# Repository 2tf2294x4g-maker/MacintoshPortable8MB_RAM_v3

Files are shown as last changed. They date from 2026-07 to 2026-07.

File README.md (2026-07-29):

# Mac Portable 8MB RAM Card (v3 — All-5V)

Expands a Macintosh Portable to **9 MB total** (1 MB onboard + 8 MB this card) — the maximum the Portable's address space supports.

All-5V design using 1M×8 SRAM chips and an ATF1502ASL CPLD. Works with both the **M5120** (non-backlit) and **M5126** (backlit) Portable via the MODEL jumper. Banks are added sequentially — no jumpers needed as you populate.

> ⚠️ **PRE-PRODUCTION — NOT TESTED**
> This board has been designed and ordered but has not yet been assembled or validated on real hardware. Schematics, firmware, and Gerbers are provided as-is. Do not build for production use until hardware validation is complete.

---

## What's new in v3 vs v2

| | v2 | v3 |
|---|---|---|
| Model compatibility | M5120 only | M5120 + M5126 (MODEL jumper) |
| Bank indicator | none | 4 green latching LEDs (one per bank) |
| Ghost RAM protection | none | 10 KΩ pull-downs on SD0–SD15 |
| Population jumper | SIZE jumper (JP1) | none — sequential by design |
| DTACK output | bodge wire to CPLD pad | J3 header (pin 1 = /DTACK, pin 2 = /EXT_DTACK) |
| SRAM count | 8× AS6C8008 | 8× AS6C8008 (same chips) |

---

## Specs

| | |
|---|---|
| Capacity | 8 MB (8× 1M×8 SRAM) |
| System total | 9 MB M5120 (open) / 7 MB M5126 (closed) |
| Bus width | 16-bit (two 8-bit SRAMs per bank) |
| Banks | 4 × 2 MB, populated sequentially |
| Logic | ATF1502ASL CPLD (5V, TQFP-44) |
| SRAM | 8× AS6C8008-55ZIN (5V, TSOP-II-44) |
| Layers | 4 (F.Cu signal / GND plane / +5V plane / B.Cu signal) |
| Connector | Samtec BCS-125-F-D-HE (50-pin 2×25, horizontal entry) |
| MODEL jumper | JP1: OPEN = M5120 non-backlit (9 MB) / CLOSED = M5126 backlit (7 MB) |

---

## Bill of Materials

| Ref | Qty | Value | Package | Part / Notes |
|-----|----:|---|---|---|
| U1–U8 | 8 | AS6C8008-55ZIN | TSOP-II-44 | Alliance Memory — 1M×8 5V SRAM 55 ns. Order spares. |
| U9 | 1 | ATF1502ASL | TQFP-44 | Microchip ATF1502ASL-**25AU44** — must be **ASL** (5V), not ASV |
| U10, U11 | 2 | 74HC245 | SOIC-20 **wide** | SN74HC245**DW** — verify wide (7.5 mm) body |
| J1 | 1 | RAM connector | Samtec BCS-125-F-D-HE | 50-pin socket, horizontal entry |
| J2 | 1 | JTAG header | 1×6 2.54 mm pin header | GND/VCC/TDO/TDI/TMS/TCK left-to-right |
| J3 | 1 | PDS DTACK header | 1×2 2.54 mm pin header | Pin 1 = /DTACK → PDS B7, Pin 2 = /EXT_DTACK → PDS B30 |
| JP1 | 1 | MODEL jumper | 1×2 2.54 mm pin header + shunt | OPEN = M5120 / CLOSED = M5126 |
| D1–D4 | 4 | Green LED | 0603 | Latch ON at boot when each bank is confirmed by the CPLD |
| R1–R4 | 4 | 330 Ω | 0402 | Series resistors for D1–D4 |
| R5–R20 | 16 | 10 KΩ | 0402 | Pull-downs on SD0–SD15 (SRAM side of 74HC245) — prevent ghost RAM |
| R21–R24 | 4 | 10 KΩ | 0805 | Pull-ups on CPLD unused inputs and MODEL jumper pin |
| C1–C14 | 14 | 100 nF | 0805 | X7R 50V ceramic bypass (one per IC) |
| C15–C19 | 5 | 10 µF | 0805 | X5R 16V ceramic bulk |

Full BOM: [PortableRAM-8MB-v3-BOM.csv](PortableRAM-8MB-v3-BOM.csv)

---

## ⚠️ Important — SRAM Pinout

The AS6C8008 (1M×8) and AS7C4096A (512K×8 used in the 4MB card) are **both TSOP-II-44 but have different pinouts**. Do not mix them between boards.

---

## Population Guide

Banks are populated sequentially — each pair of SRAMs adds 2 MB. No jumpers required.

| Step | Chips | Total RAM |
|---|---|---|
| 1 | U1 + U5 | 2 MB |
| 2 | U2 + U6 | 4 MB |
| 3 | U3 + U7 | 6 MB |
| 4 | U4 + U8 | 8 MB |

The green LED for each bank (D1–D4) latches on at boot when the CPLD confirms that bank is active. A dark LED means the bank is not yet populated.

---

## MODEL Jumper (JP1)

| JP1 | Portable model | System RAM |
|-----|---|---|
| Open (no shunt) | M5120 non-backlit | 9 MB |
| Closed (shunt installed) | M5126 backlit | 7 MB |

The M5126 uses slot CS0 for its backlight controller, which conflicts with the top 2 MB bank. Closing JP1 disables that bank so the two don't fight. Leave open for M5120.

---

## Files

```
PortableRAM-8MB.kicad_pcb     — PCB layout (KiCad 9)
PortableRAM-8MB.kicad_sch     — Schematic
PortableRAM-8MB.kicad_pro     — Project file
PortableRAM.kicad_sym         — Custom symbol library
PortableRAM.pretty/           — Custom footprint library
Library.pretty/               — Additional footprints
Gerbers/                      — Gerber + drill files (ready to order)
PortableRAM-8MB-v3-Gerbers.zip — Same, zipped (upload directly to fab)
firmware/
  PortableRAM8_v3.pld            — CUPL source (ATF1502ASL logic)
  PortableRAM8_v3.jed            — Compiled JEDEC fusemap
  PortableRAM8_v3.svf            — SVF for OpenOCD programming
  PortableRAM8_v3.fit            — WinCUPL fit report
  program.sh                  — One-command programming script (Tigard)
  BUILD.md                    — Firmware build instructions (WinCUPL + Wine)
PortableRAM-8MB-v3-BOM.csv
```

---

## Ordering the PCB

Upload `PortableRAM-8MB-v3-Gerbers.zip` to your preferred fab (JLCPCB, PCBWay, OSHPark, etc.).

**Board settings:**
- Layers: **4**
- Thickness: 1.6 mm
- Surface finish: **ENIG** (recommended — fine-pitch 0.8 mm pads on TSOP-II-44 and TQFP-44)
- All other settings: fab defaults

---

## Assembly Notes

Solder in this order:

1. **U9** (ATF1502ASL CPLD, TQFP-44) — center first, then drag-solder
2. **U1–U8** (SRAM, TSOP-II-44) — fine pitch; flux generously. Populate in bank pairs: U1+U5 → U2+U6 → U3+U7 → U4+U8
3. **U10, U11** (74HC245, SOIC-20 wide)
4. **R5–R20** (10 KΩ 0402 pull-downs)
5. **R1–R4** (330 Ω 0402 LED resistors)
6. **R21–R24** (10 KΩ 0805 pull-ups)
7. **C1–C14** (100 nF 0805 bypass caps)
8. **C15–C19** (10 µF 0805 bulk caps)
9. **D1–D4** (green 0603 LEDs — observe polarity)
10. **JP1** (1×2 header — add shunt for M5126, leave open for M5120)
11. **J2** (1×6 JTAG header)
12. **J3** (1×2 PDS DTACK header — on board edge)
13. **J1** (Samtec connector) — last

---

## Programming the CPLD

The ATF1502ASL must be programmed before the card will work. Use J2 (1×6 header on the board edge).

### J2 pinout (left to right, component side)

| Pin | Signal |
|-----|---|
| 1 | GND |
| 2 | VCC |
| 3 | TDO |
| 4 | TDI |
| 5 | TMS |
| 6 | TCK |

### With a Tigard programmer (FT2232H-based)

Set the Tigard voltage jumper to **5V** before connecting.

```bash
cd firmware
./program.sh PortableRAM8_v3.svf
```

Success output ends with `shutdown command invoked` and no TDO mismatch errors.

See [firmware/BUILD.md](firmware/BUILD.md) for the full build and programming pipeline (WinCUPL + Wine on Linux, prjbureau for SVF generation).

---

## Installation

1. Power off and unplug the Mac Portable.
2. Remove the battery and bottom cover.
3. Set JP1 (MODEL jumper) for your machine — open for M5120, closed for M5126.
4. Seat the card on the RAM expansion header — J1 is a friction-fit horizontal-entry socket.
5. Reassemble and power on.

With a full build (all 8 SRAMs), you should see **9 MB** in About This Macintosh (M5120) or **7 MB** (M5126). All four green LEDs D1–D4 will be lit.

### DTACK Performance Fix — J3 header

The Mac Portable's GLU chip generates /DTACK for the 68000 with region-dependent timing:

| Address range | GLU /DTACK | Condition |
|---|---|---|
| 0x000000–0x4FFFFF | 2 clocks | Always — hardwired fast path |
| 0x500000–0x8FFFFF | 6 clocks | Normal operation (register configured) |
| 0x500000–0x8FFFFF | 18 clocks | After sleep/wake (register reset) |

The 8 MB card spans 0x100000–0x8FFFFF, straddling the split. Banks 0–1 (0x100000–0x4FFFFF) already get the GLU's 2-clock fast path. Banks 2–3 (0x500000–0x8FFFFF) run at 6 clocks and collapse to 18 clocks after sleep/wake when the GLU's DTACK register loses its configuration.

The fix is built into v3: the CPLD asserts /DTACK directly via **J3 pin 1**, bypassing the GLU for all card accesses. Connect a wire from J3 pin 1 to **PDS slot pin B7** (/DTACK) on the Mac Portable motherboard. The CPLD's path is purely combinatorial — faster than even the GLU's 2-clock mode — and immune to sleep/wake state loss.

J3 pin 2 (/EXT_DTACK → PDS B30) is an optional second output for experimentation.

**Validated on v2 hardware (July 2026):**

| Configuration | Speedometer | Snooper | Post-sleep |
|---|---|---|---|
| 1 MB card (baseline) | 1.990 | 87% | 1.985 |
| 8 MB card — no DTACK fix | 1.486 | 51% | 0.974 / 22% |
| **8 MB card + CPLD DTACK** | **2.170** | **102%** | **2.170** |
| **4 MB card + CPLD DTACK** | **2.170** | **102%** | **2.170** |

The CPLD outperforms the GLU's fastest mode (102% vs 87% baseline) because its combinatorial propagation delay is well under one bus clock. Post-sleep collapse is fully eliminated. The 4 MB result confirms the CPLD path is faster than even the GLU's hardwired 2-clock mode — the fix benefits all bank configurations, not just the upper 8 MB range.

The PDS connector is the 96-pin DIN-41612 on the Mac Portable motherboard (3 rows A/B/C, 32 pins each). Pin B7 is in row B, position 7 from the component side.

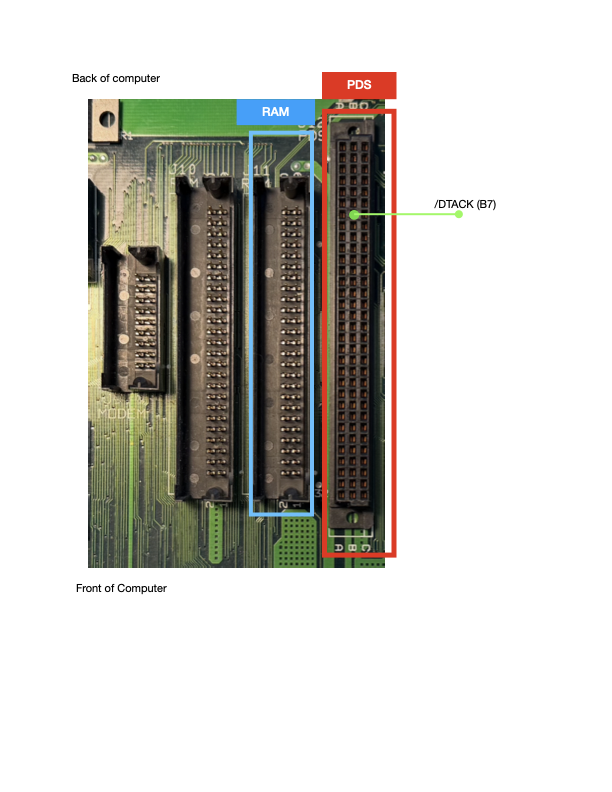
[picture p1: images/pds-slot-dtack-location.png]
PDS slot and RAM connector locations, with /DTACK (B7) marked


---

## References & Acknowledgements

**Dynamic Engineering Mac Portable RAM Card**
The address decode and bus control logic in `PortableRAM8_v3.pld` is derived from GAL22V10 PLD source files originally written for the Dynamic Engineering commercial RAM expansion card. These files define the core signal equations — bank chip-select generation, byte-lane write control via UDS*/LDS*, bus transceiver direction, and output enable timing. The original `.PLD` files were recovered and shared by *techknight* on the TinkerDifferent forum and #skunkworks Discord. Translated here from three GAL22V10 chips to a single ATF1502ASL CPLD, with corrections to the `r_w_u` equation and address decode base, and extended for 8MB capacity and M5126 compatibility.

**miejas — Macintosh Portable 4MB Memory Expansion**
[https://github.com/miejas/Macintosh-Portable-4-MB-Memory-Expansion](https://github.com/miejas/Macintosh-Portable-4-MB-Memory-Expansion)
Open-source 4MB RAM card used as a cross-reference for connector pinout, bus transceiver approach, and firmware structure.

**Reza Fouladian — PortableRAM BGA 8MB**
[https://github.com/rezafouladian/PortableRAM-BGA-8MB](https://github.com/rezafouladian/PortableRAM-BGA-8MB)
BGA-format 8MB card using the ATF1502ASV (3.3V CPLD) and SN74LVC4245A level translators. Reference for the 8MB address decode strategy and CPLD pin planning. Reza also provided direct guidance on driving /DTACK from the CPLD and on the Mac Portable PDS connector pinout — specifically confirming that /DTACK is available on PDS pin B7 and can be driven directly from a CPLD output. This insight is the basis for the J3 DTACK header on v3 and the validated bodge fix on v2.

**Apple Mac Portable Developer Notes & Schematics**
Apple's original hardware documentation for the Mac Portable expansion bus, memory map, and GLU register behaviour (including the $FC0200 DTACK register).

---

## License

Hardware released under [CERN-OHL-S v2](https://ohwr.org/cern_ohl_s_v2.txt). Firmware source (`PortableRAM8_v3.pld`) released under MIT.

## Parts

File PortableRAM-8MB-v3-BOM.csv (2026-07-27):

Designator | Qty | Value | Package | Manufacturer | Mfr Part Number | Notes
U1,U2,U3,U4,U5,U6,U7,U8 | 8 | AS6C8008-55ZIN | TSOP-II-44 (10.16x18.41mm P0.8mm) | Alliance Memory | AS6C8008-55ZIN | 1Mx8 SRAM 5V 55ns (Z=TSOP-II pkg); ~$13-15 each; order 1-2 spares; populate sequentially: U1+U5=2MB U2+U6=4MB U3+U7=6MB U4+U8=8MB
U9 | 1 | ATF1502ASL | TQFP-44 (10x10mm P0.8mm) | Microchip | ATF1502ASL-25AU44 | 5V CPLD (ASL = 5V; do NOT order ASV which is 3.3V); program via J2 JTAG header; order a spare
U10,U11 | 2 | 74HC245 | SOIC-20W (7.5mm wide) | TI/Nexperia | SN74HC245DW | Octal bus transceiver 5V; verify WIDE SOIC-20 body (DW/DWR suffix)
J1 | 1 | RAM Connector | Samtec BCS-125-F-D-HE | Samtec | BCS-125-F-D-HE | 50-pin 2x25 2.54mm socket strip; footprint verified vs drawing
J2 | 1 | JTAG Header 1x06 | PinHeader 2.54mm 1x06 vertical | Generic |  | GND/VCC/TDO/TDI/TMS/TCK left-to-right; labeled on silkscreen; for Tigard programmer
J3 | 1 | PDS DTACK header 1x02 | PinHeader 2.54mm 1x02 vertical | Generic |  | Pin 1 = /DTACK -> PDS B7; Pin 2 = /EXT_DTACK -> PDS B30 (optional)
JP1 | 1 | MODEL jumper 1x02 | PinHeader 2.54mm 1x02 vertical | Generic |  | OPEN=M5120 non-backlit (9MB total) / CLOSED=M5126 backlit (7MB total). Add one 2.54mm shunt.
D1,D2,D3,D4 | 4 | GREEN LED | LED_0603 (1608 metric) | Generic |  | Green indicator LEDs; latch ON when Mac boot probe confirms each bank; board top edge
R1,R2,R3,R4 | 4 | 330 | R_0402 (1005 metric) | Generic |  | Series resistors for D1-D4 LEDs; 330 ohm 1% 1/16W
R5,R6,R7,R8,R9,R10,R11,R12,R13,R14,R15,R16,R17,R18,R19,R20 | 16 | 10K | R_0402 (1005 metric) | Generic |  | Pull-down resistors on SD0-SD15 data bus (SRAM side of 74HC245); prevent ghost RAM on unpopulated banks
R21,R22,R23,R24 | 4 | 10K | R_0805 (2012 metric) | Generic |  | Pull-up resistors on CPLD unused inputs (/AS /DELAY_CS /SLEEP) and MODEL jumper JP1 pin; 5% thick film
C1,C2,C3,C4,C5,C6,C7,C8,C9,C10,C11,C12,C13,C14 | 14 | 100nF | C_0805 (2012 metric) | Generic |  | X7R 50V ceramic decoupling; one per SRAM + U9 + U10 + U11; buy strip of 50+
C15,C16,C17,C18,C19 | 5 | 10uF | C_0805 (2012 metric) | Generic |  | X5R 16V ceramic bulk decoupling; buy 10+

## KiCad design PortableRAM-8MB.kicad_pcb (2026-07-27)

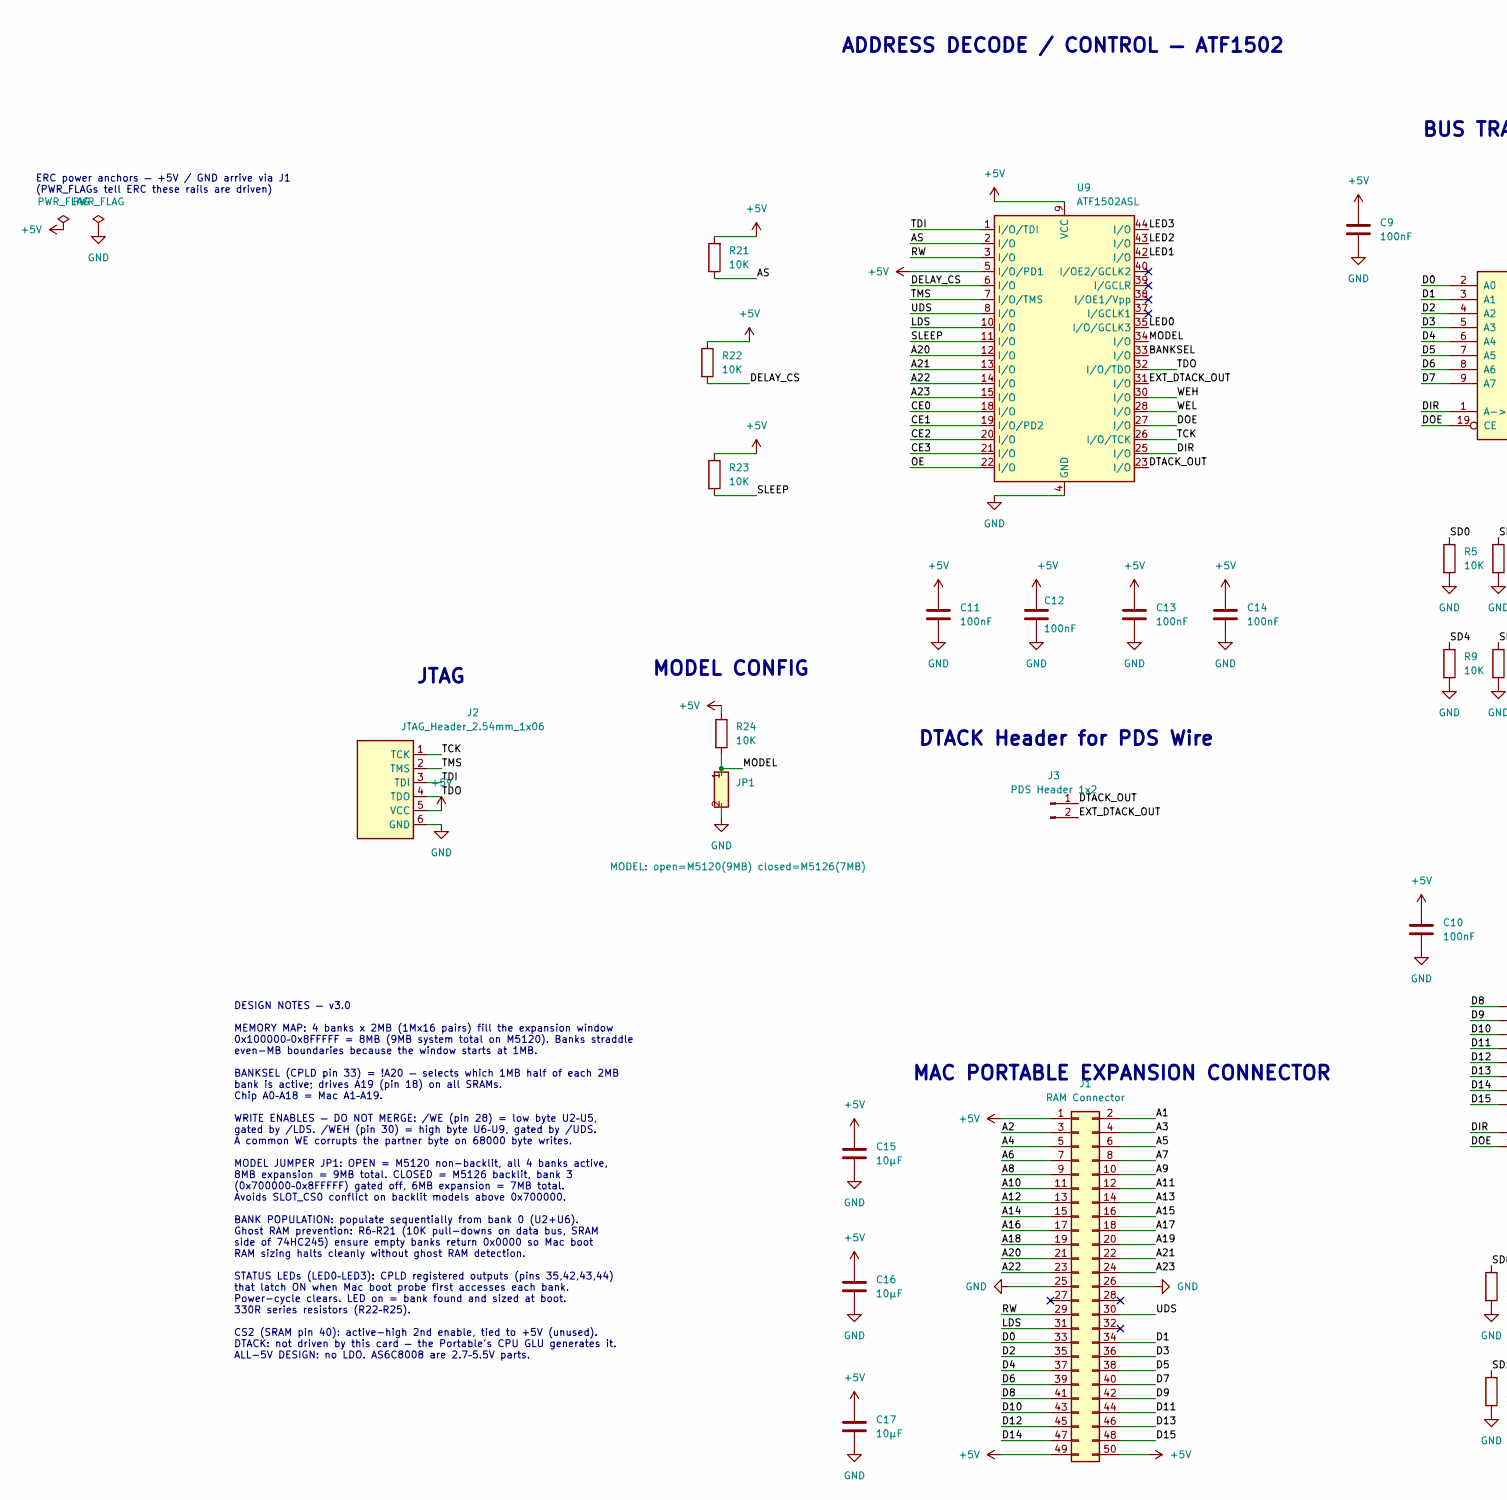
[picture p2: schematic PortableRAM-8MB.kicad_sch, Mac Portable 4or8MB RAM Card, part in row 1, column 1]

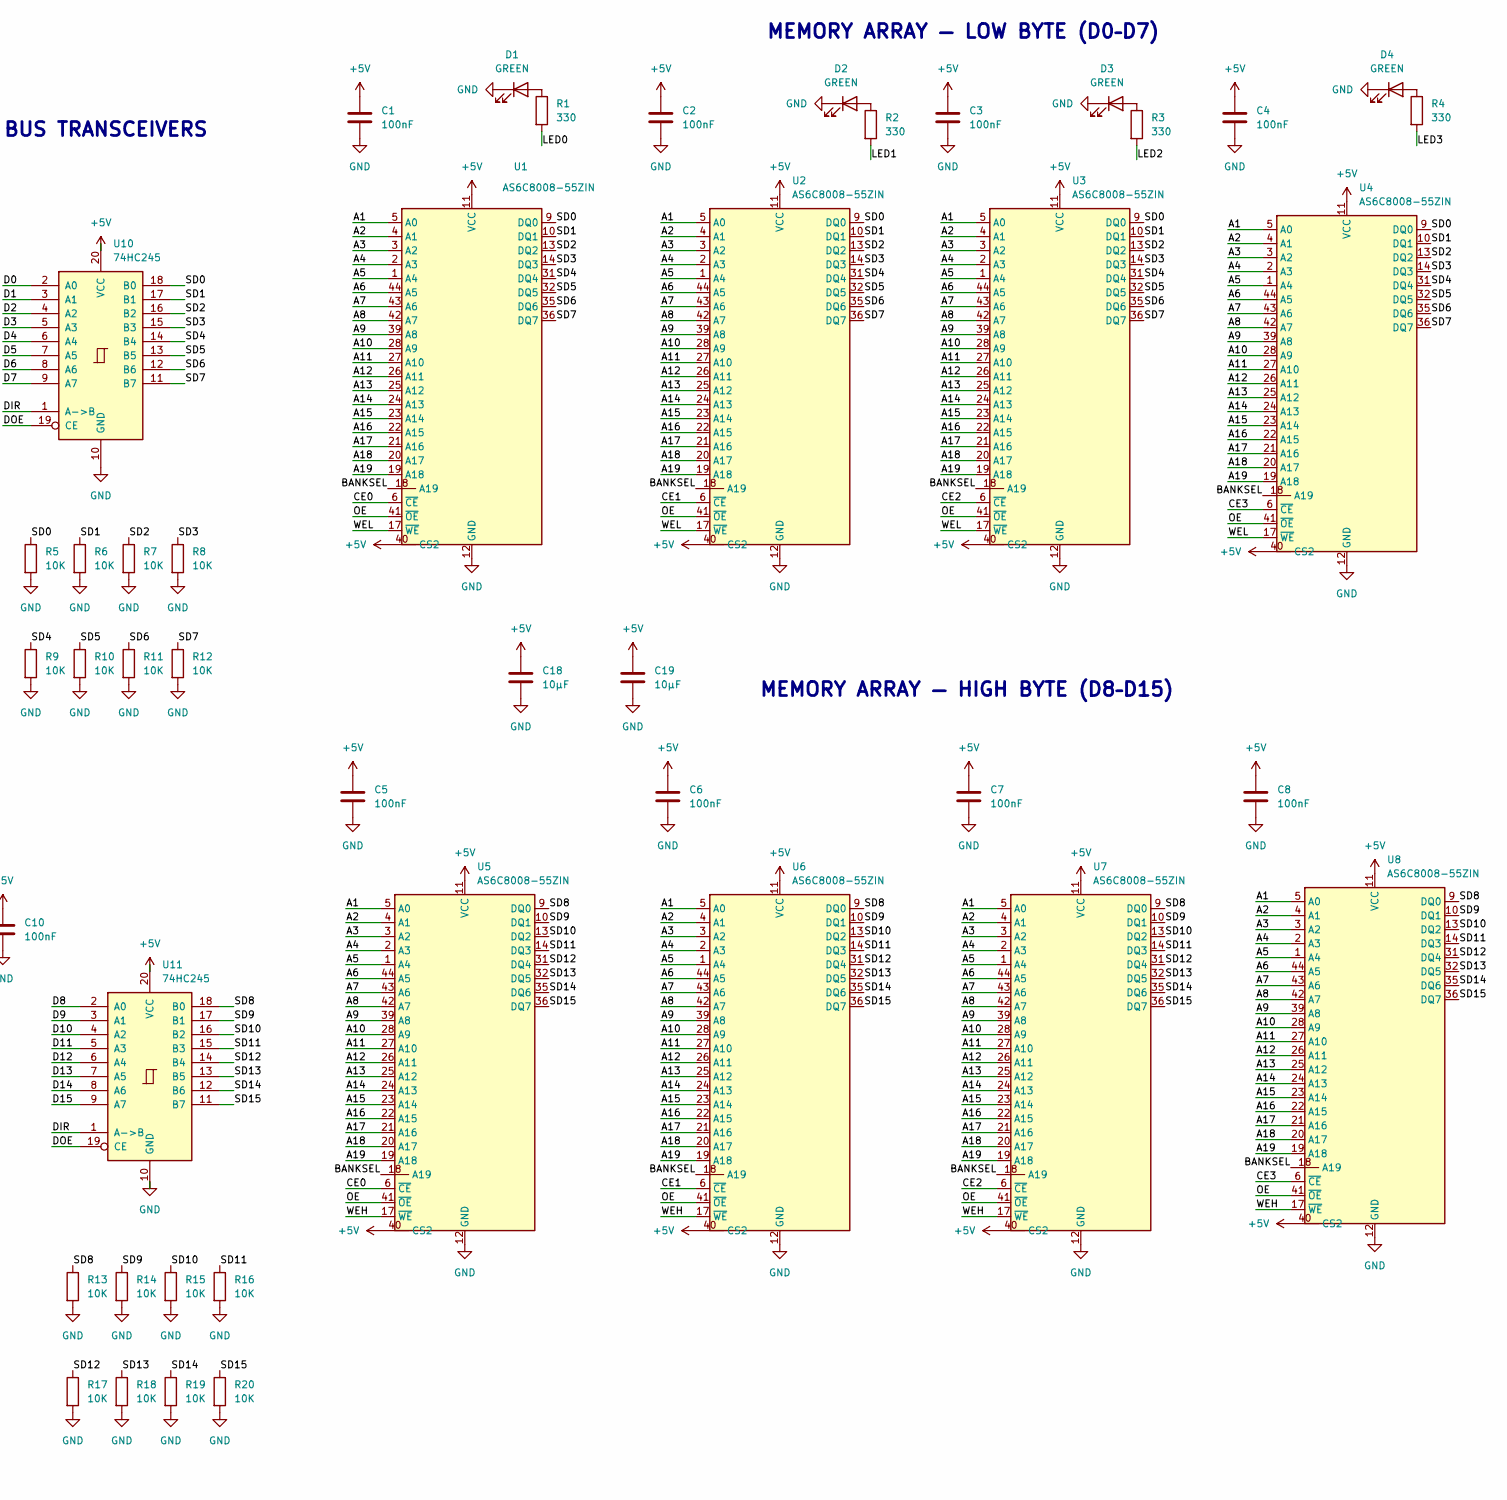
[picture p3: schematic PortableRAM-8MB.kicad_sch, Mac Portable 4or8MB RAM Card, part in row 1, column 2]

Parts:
C1, C2, C3, C4, C5, C6, C7, C8, C9, C10, C11, C12, C13, C14: 100nF; C_0805_2012Metric
C15, C16, C17, C18, C19: 10µF; C_0805_2012Metric
D1, D2, D3, D4: GREEN; LED_0603_1608Metric
J1: RAM Connector; Samtec_BCS-125-F-D-HE
J2: JTAG_Header_2.54mm_1x06; PinHeader_1x06_P2.54mm_Vertical
J3: PDS Header 1x2; PinHeader_1x02_P2.54mm_Vertical
JP1: MODEL: open=M5120(9MB) closed=M5126(7MB); PinHeader_1x02_P2.54mm_Vertical
R1, R2, R3, R4: 330; R_0402_1005Metric
R5, R6, R7, R8, R9, R10, R11, R12, R13, R14, R15, R16, R17, R18, R19, R20: 10K; R_0402_1005Metric
R21, R22, R23, R24: 10K; R_0805_2012Metric
U1, U2, U3, U4, U5, U6, U7, U8: AS6C8008-55ZIN; TSOP-II-44_10.16x18.41mm_P0.8mm
U9: ATF1502ASL; TQFP-44_10x10mm_P0.8mm
U10, U11: 74HC245; SOIC-20W_7.5x12.8mm_P1.27mm

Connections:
+5V: C1.1, C2.1, C3.1, C4.1, C5.1, C6.1, C7.1, C8.1, C9.1, C10.1, C11.1, C12.1, C13.1, C14.1, C15.1, C16.1, C17.1, C18.1, C19.1, J1.1, J1.49, J1.50, J2.5 (VCC), R21.2, R22.1, R23.1, R24.1, U1.11 (VCC), U1.33 (VCC), U1.40 (CS2), U2.11 (VCC), U2.33 (VCC), U2.40 (CS2), U3.11 (VCC), U3.33 (VCC), U3.40 (CS2), U4.11 (VCC), U4.33 (VCC), U4.40 (CS2), U5.11 (VCC), U5.33 (VCC), U5.40 (CS2), U6.11 (VCC), U6.33 (VCC), U6.40 (CS2), U7.11 (VCC), U7.33 (VCC), U7.40 (CS2), U8.11 (VCC), U8.33 (VCC), U8.40 (CS2), U9.5 (I/O/PD1), U9.9 (VCC), U9.17 (VCC), U9.29 (VCC), U9.41 (VCC), U10.20 (VCC), U11.20 (VCC)
/A1: J1.2, U1.5 (A0), U2.5 (A0), U3.5 (A0), U4.5 (A0), U5.5 (A0), U6.5 (A0), U7.5 (A0), U8.5 (A0)
/A2: J1.3, U1.4 (A1), U2.4 (A1), U3.4 (A1), U4.4 (A1), U5.4 (A1), U6.4 (A1), U7.4 (A1), U8.4 (A1)
/A3: J1.4, U1.3 (A2), U2.3 (A2), U3.3 (A2), U4.3 (A2), U5.3 (A2), U6.3 (A2), U7.3 (A2), U8.3 (A2)
/A4: J1.5, U1.2 (A3), U2.2 (A3), U3.2 (A3), U4.2 (A3), U5.2 (A3), U6.2 (A3), U7.2 (A3), U8.2 (A3)
/A5: J1.6, U1.1 (A4), U2.1 (A4), U3.1 (A4), U4.1 (A4), U5.1 (A4), U6.1 (A4), U7.1 (A4), U8.1 (A4)
/A6: J1.7, U1.44 (A5), U2.44 (A5), U3.44 (A5), U4.44 (A5), U5.44 (A5), U6.44 (A5), U7.44 (A5), U8.44 (A5)
/A7: J1.8, U1.43 (A6), U2.43 (A6), U3.43 (A6), U4.43 (A6), U5.43 (A6), U6.43 (A6), U7.43 (A6), U8.43 (A6)
/A8: J1.9, U1.42 (A7), U2.42 (A7), U3.42 (A7), U4.42 (A7), U5.42 (A7), U6.42 (A7), U7.42 (A7), U8.42 (A7)
/A9: J1.10, U1.39 (A8), U2.39 (A8), U3.39 (A8), U4.39 (A8), U5.39 (A8), U6.39 (A8), U7.39 (A8), U8.39 (A8)
/A10: J1.11, U1.28 (A9), U2.28 (A9), U3.28 (A9), U4.28 (A9), U5.28 (A9), U6.28 (A9), U7.28 (A9), U8.28 (A9)
/A11: J1.12, U1.27 (A10), U2.27 (A10), U3.27 (A10), U4.27 (A10), U5.27 (A10), U6.27 (A10), U7.27 (A10), U8.27 (A10)
/A12: J1.13, U1.26 (A11), U2.26 (A11), U3.26 (A11), U4.26 (A11), U5.26 (A11), U6.26 (A11), U7.26 (A11), U8.26 (A11)
/A13: J1.14, U1.25 (A12), U2.25 (A12), U3.25 (A12), U4.25 (A12), U5.25 (A12), U6.25 (A12), U7.25 (A12), U8.25 (A12)
/A14: J1.15, U1.24 (A13), U2.24 (A13), U3.24 (A13), U4.24 (A13), U5.24 (A13), U6.24 (A13), U7.24 (A13), U8.24 (A13)
/A15: J1.16, U1.23 (A14), U2.23 (A14), U3.23 (A14), U4.23 (A14), U5.23 (A14), U6.23 (A14), U7.23 (A14), U8.23 (A14)
/A16: J1.17, U1.22 (A15), U2.22 (A15), U3.22 (A15), U4.22 (A15), U5.22 (A15), U6.22 (A15), U7.22 (A15), U8.22 (A15)
/A17: J1.18, U1.21 (A16), U2.21 (A16), U3.21 (A16), U4.21 (A16), U5.21 (A16), U6.21 (A16), U7.21 (A16), U8.21 (A16)
/A18: J1.19, U1.20 (A17), U2.20 (A17), U3.20 (A17), U4.20 (A17), U5.20 (A17), U6.20 (A17), U7.20 (A17), U8.20 (A17)
/A19: J1.20, U1.19 (A18), U2.19 (A18), U3.19 (A18), U4.19 (A18), U5.19 (A18), U6.19 (A18), U7.19 (A18), U8.19 (A18)
/A20: J1.21, U9.12 (I/O)
/A21: J1.22, U9.13 (I/O)
/A22: J1.23, U9.14 (I/O)
/A23: J1.24, U9.15 (I/O)
/AS: R21.1, U9.2 (I/O)
/BANKSEL: U1.18 (A19), U2.18 (A19), U3.18 (A19), U4.18 (A19), U5.18 (A19), U6.18 (A19), U7.18 (A19), U8.18 (A19), U9.33 (I/O)
/CE0: U1.6 (~CE), U5.6 (~CE), U9.18 (I/O)
/CE1: U2.6 (~CE), U6.6 (~CE), U9.19 (I/O/PD2)
/CE2: U3.6 (~CE), U7.6 (~CE), U9.20 (I/O)
/CE3: U4.6 (~CE), U8.6 (~CE), U9.21 (I/O)
/D0: J1.33, U10.2 (A0)
/D1: J1.34, U10.3 (A1)
/D2: J1.35, U10.4 (A2)
/D3: J1.36, U10.5 (A3)
/D4: J1.37, U10.6 (A4)
/D5: J1.38, U10.7 (A5)
/D6: J1.39, U10.8 (A6)
/D7: J1.40, U10.9 (A7)
/D8: J1.41, U11.2 (A0)
/D9: J1.42, U11.3 (A1)
/D10: J1.43, U11.4 (A2)
/D11: J1.44, U11.5 (A3)
/D12: J1.45, U11.6 (A4)
/D13: J1.46, U11.7 (A5)
/D14: J1.47, U11.8 (A6)
/D15: J1.48, U11.9 (A7)
/DELAY_CS: R22.2, U9.6 (I/O)
/DIR: U9.25 (I/O), U10.1 (A->B), U11.1 (A->B)
/DOE: U9.27 (I/O), U10.19 (CE), U11.19 (CE)
/DTACK_OUT: J3.1, U9.23 (I/O)
/EXT_DTACK_OUT: J3.2, U9.31 (I/O)
/LDS: J1.31, U9.10 (I/O)
/LED0: R1.2, U9.35 (I/O/GCLK3)
/LED1: R2.2, U9.42 (I/O)
/LED2: R3.2, U9.43 (I/O)
/LED3: R4.2, U9.44 (I/O)
/MODEL: JP1.1, R24.2, U9.34 (I/O)
/OE: U1.41 (~OE), U2.41 (~OE), U3.41 (~OE), U4.41 (~OE), U5.41 (~OE), U6.41 (~OE), U7.41 (~OE), U8.41 (~OE), U9.22 (I/O)
/RW: J1.29, U9.3 (I/O)
/SD0: R5.1, U1.9 (DQ0), U2.9 (DQ0), U3.9 (DQ0), U4.9 (DQ0), U10.18 (B0)
/SD1: R6.1, U1.10 (DQ1), U2.10 (DQ1), U3.10 (DQ1), U4.10 (DQ1), U10.17 (B1)
/SD2: R7.1, U1.13 (DQ2), U2.13 (DQ2), U3.13 (DQ2), U4.13 (DQ2), U10.16 (B2)
/SD3: R8.1, U1.14 (DQ3), U2.14 (DQ3), U3.14 (DQ3), U4.14 (DQ3), U10.15 (B3)
/SD4: R9.1, U1.31 (DQ4), U2.31 (DQ4), U3.31 (DQ4), U4.31 (DQ4), U10.14 (B4)
/SD5: R10.1, U1.32 (DQ5), U2.32 (DQ5), U3.32 (DQ5), U4.32 (DQ5), U10.13 (B5)
/SD6: R11.1, U1.35 (DQ6), U2.35 (DQ6), U3.35 (DQ6), U4.35 (DQ6), U10.12 (B6)
/SD7: R12.1, U1.36 (DQ7), U2.36 (DQ7), U3.36 (DQ7), U4.36 (DQ7), U10.11 (B7)
/SD8: R13.1, U5.9 (DQ0), U6.9 (DQ0), U7.9 (DQ0), U8.9 (DQ0), U11.18 (B0)
/SD9: R14.1, U5.10 (DQ1), U6.10 (DQ1), U7.10 (DQ1), U8.10 (DQ1), U11.17 (B1)
/SD10: R15.1, U5.13 (DQ2), U6.13 (DQ2), U7.13 (DQ2), U8.13 (DQ2), U11.16 (B2)
/SD11: R16.1, U5.14 (DQ3), U6.14 (DQ3), U7.14 (DQ3), U8.14 (DQ3), U11.15 (B3)
/SD12: R17.1, U5.31 (DQ4), U6.31 (DQ4), U7.31 (DQ4), U8.31 (DQ4), U11.14 (B4)
/SD13: R18.1, U5.32 (DQ5), U6.32 (DQ5), U7.32 (DQ5), U8.32 (DQ5), U11.13 (B5)
/SD14: R19.1, U5.35 (DQ6), U6.35 (DQ6), U7.35 (DQ6), U8.35 (DQ6), U11.12 (B6)
/SD15: R20.1, U5.36 (DQ7), U6.36 (DQ7), U7.36 (DQ7), U8.36 (DQ7), U11.11 (B7)
/SLEEP: R23.2, U9.11 (I/O)
/TCK: J2.1 (TCK), U9.26 (I/O/TCK)
/TDI: J2.3 (TDI), U9.1 (I/O/TDI)
/TDO: J2.4 (TDO), U9.32 (I/O/TDO)
/TMS: J2.2 (TMS), U9.7 (I/O/TMS)
/UDS: J1.30, U9.8 (I/O)
/WEH: U5.17 (~WE), U6.17 (~WE), U7.17 (~WE), U8.17 (~WE), U9.30 (I/O)
/WEL: U1.17 (~WE), U2.17 (~WE), U3.17 (~WE), U4.17 (~WE), U9.28 (I/O)
GND: C1.2, C2.2, C3.2, C4.2, C5.2, C6.2, C7.2, C8.2, C9.2, C10.2, C11.2, C12.2, C13.2, C14.2, C15.2, C16.2, C17.2, C18.2, C19.2, D1.1 (K), D2.1 (K), D3.1 (K), D4.1 (K), J1.25, J1.26, J2.6 (GND), JP1.2, R5.2, R6.2, R7.2, R8.2, R9.2, R10.2, R11.2, R12.2, R13.2, R14.2, R15.2, R16.2, R17.2, R18.2, R19.2, R20.2, U1.12 (GND), U1.34 (GND), U2.12 (GND), U2.34 (GND), U3.12 (GND), U3.34 (GND), U4.12 (GND), U4.34 (GND), U5.12 (GND), U5.34 (GND), U6.12 (GND), U6.34 (GND), U7.12 (GND), U7.34 (GND), U8.12 (GND), U8.34 (GND), U9.4 (GND), U9.16 (GND), U9.24 (GND), U9.36 (GND), U10.10 (GND), U11.10 (GND); also elsewhere on the board
unnamed: D1.2 (A), R1.1
unnamed: D2.2 (A), R2.1
unnamed: D3.2 (A), R3.1
unnamed: D4.2 (A), R4.1

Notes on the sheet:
JTAG
MAC PORTABLE EXPANSION CONNECTOR
ADDRESS DECODE / CONTROL — ATF1502
BUS TRANSCEIVERS
MEMORY ARRAY — LOW BYTE (D0–D7)
DESIGN NOTES — v3.0 MEMORY MAP: 4 banks x 2MB (1Mx16 pairs) fill the expansion window 0x100000–0x8FFFFF = 8MB (9MB system total on M5120). Banks straddle even-MB boundaries because the window starts at 1MB. BANKSEL (CPLD pin 33) = !A20 — selects which 1MB half of each 2MB bank is active; drives A19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
MEMORY ARRAY — HIGH BYTE (D8–D15)
MODEL CONFIG
DTACK Header for PDS Wire
ERC power anchors — +5V / GND arrive via J1 (PWR_FLAGs tell ERC these rails are driven)

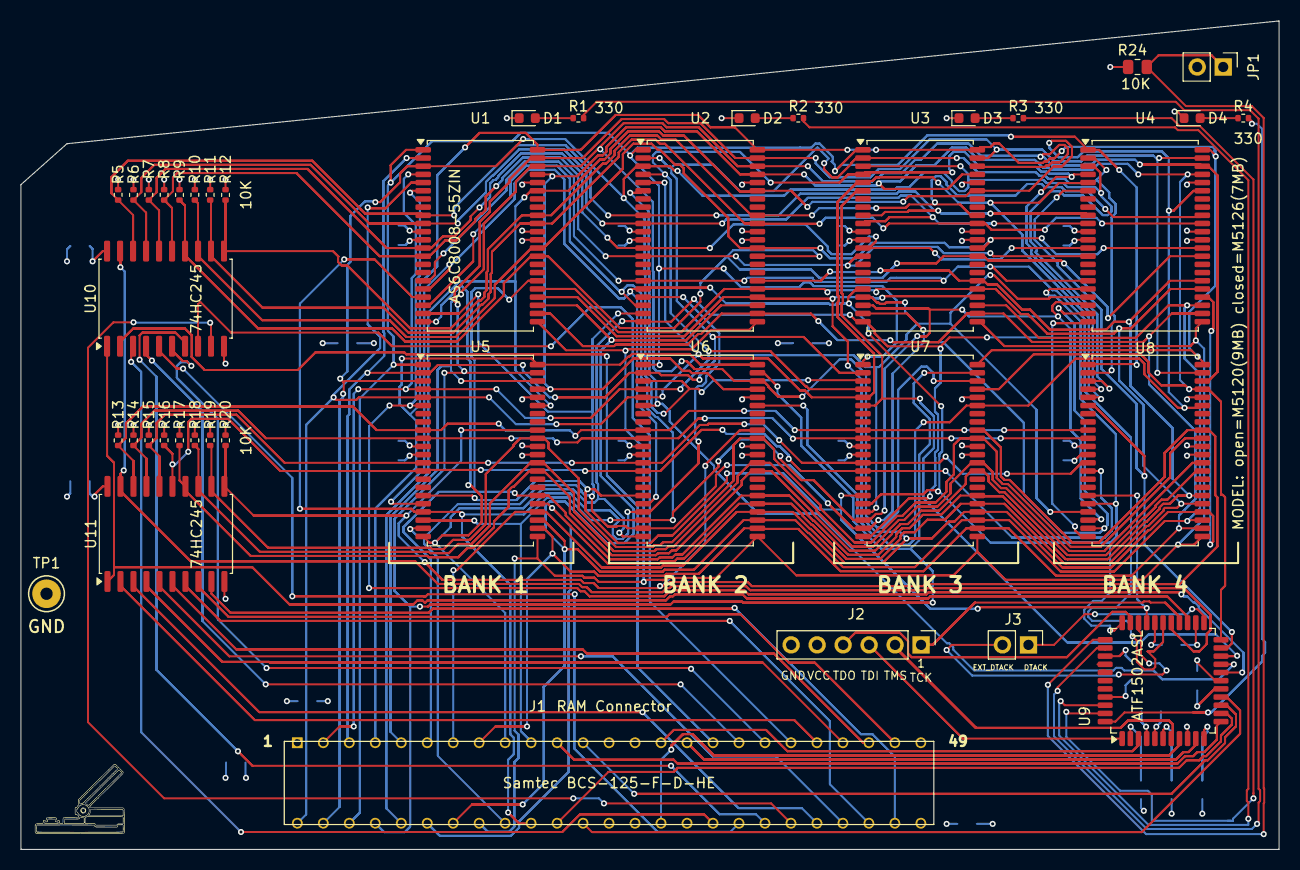
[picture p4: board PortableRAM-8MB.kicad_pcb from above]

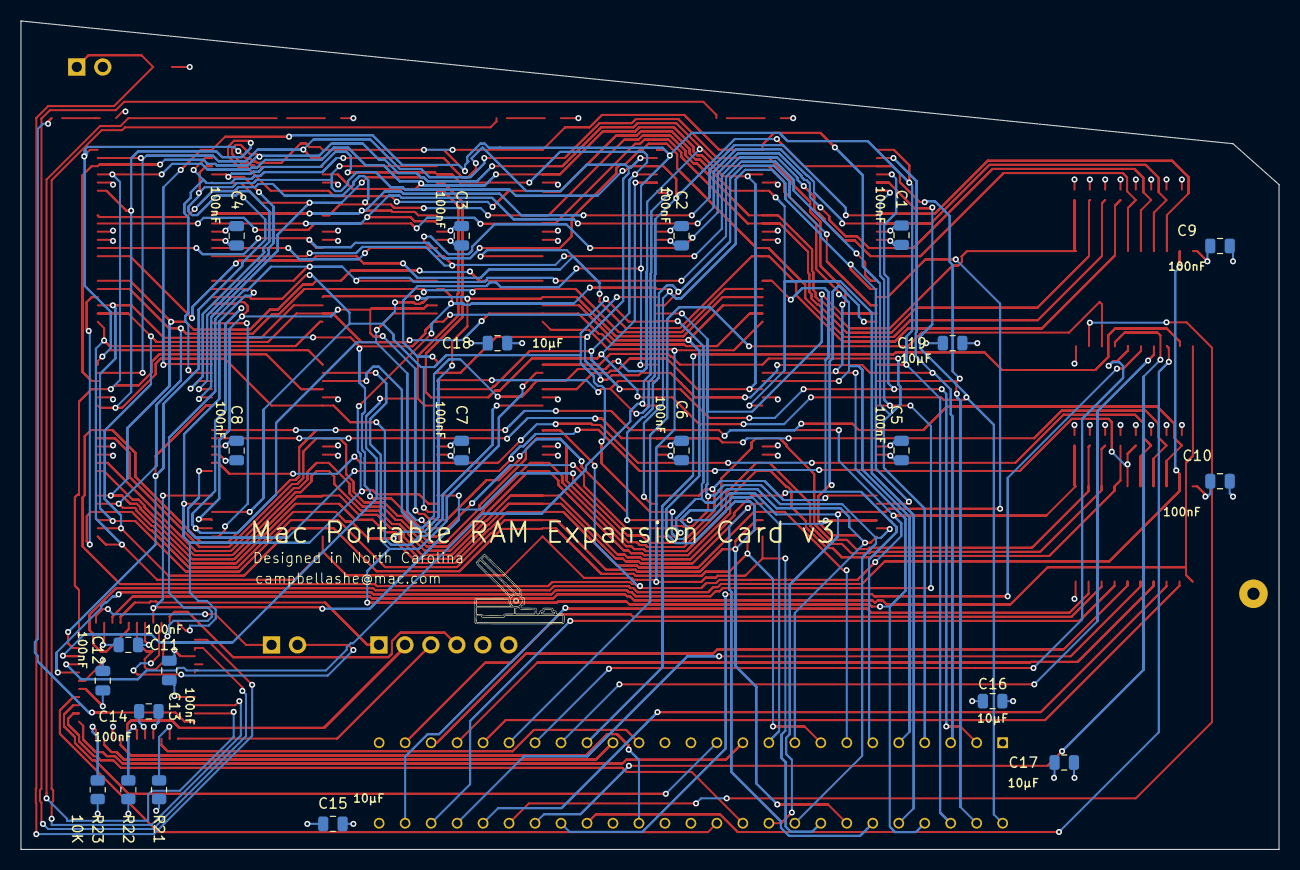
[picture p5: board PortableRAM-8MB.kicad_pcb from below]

Board: 4 copper layers, 123.0 x 81.0 mm, 63 parts (22 on the bottom side), 88 nets.

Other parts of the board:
TP1: GND; TestPoint_GND

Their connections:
GND: TP1.1; also elsewhere on the board

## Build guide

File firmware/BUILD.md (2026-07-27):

# CPLD Firmware Build — CUPL toolchain (Mac + Linux server)

WinCUPL is Windows-only, so we compile on the Ubuntu server under Wine.
Applies to `PortableRAM8.pld` — **v3 8MB board, revision 02**. Do not use with v2 source files.

## Where it's set up (server 192.168.0.52)
- SSH user: `matthew`
- Wine prefix: `~/.wine-cupl` (WINEARCH=win32) with WinCUPL installed at `C:\Wincupl`
- Fitters upgraded to **v1918** (from Atmel ProChip 5.0.1) in `C:\Wincupl\WinCupl\Fitters`
- `5vcomp` wrapper (from github peterzieba/5Vpld) at `/usr/local/bin/5vcomp`

## To compile
```
scp firmware/PortableRAM8.pld matthew@192.168.0.52:~/PortableRAM8_v3.pld
ssh matthew@192.168.0.52 'WINEPREFIX=$HOME/.wine-cupl xvfb-run -a 5vcomp PortableRAM8_v3.pld'
scp matthew@192.168.0.52:~/PortableRAM8_v3.jed firmware/PortableRAM8.jed
scp matthew@192.168.0.52:~/PortableRAM8_v3.fit firmware/PortableRAM8.fit
scp matthew@192.168.0.52:~/PortableRAM8_v3.pin firmware/PortableRAM8.pin
```
Outputs: `.jed` (program this), `.fit` (CHECK pin assignments + "JTAG = ON"), `.pin`.

## .PLD source rules (CUPL is picky — these caused real failures)
1. **Pure ASCII only** — no em-dashes (—), smart quotes, etc. CUPL chokes on UTF-8.
2. **CRLF line endings** — LF-only makes the cuplx preprocessor abort.
3. **No `*/` inside comments** — e.g. write `UDS*, LDS*` NOT `UDS*/LDS*`; the `*/`
   closes the C-style comment early and the rest parses as code.
4. **`PROPERTY ATMEL { jtag = on };`** — keeps JTAG pins live so the Tigard can
   re-program. (Default is ON for the ispTQFP44 device, but be explicit.)

## JED -> SVF (DONE — cross-platform, on the Mac, no Wine)
Uses fuseconv from whitequark/prjbureau (pure Python):
```
pip3 install --user bitarray
git clone https://github.com/whitequark/prjbureau   # has util/fuseconv.py
cd prjbureau && python3 -m prjbureau.util.fuseconv ~/PortableRAM8_v3.jed ~/PortableRAM8_v3.svf
scp matthew@192.168.0.52:~/PortableRAM8_v3.svf firmware/PortableRAM8.svf
```
The .svf self-verifies (includes readback vectors). ATF1502AS: IR length 10,
IDCODE 0x0150203f.

## Programming (when boards arrive) — Tigard + OpenOCD, on the Mac
1. `brew install open-ocd`
2. Wire Tigard JTAG to J2: TDI=pin1, TMS=pin7, TCK=pin26, TDO=pin32 (+GND, +5V sense).
3. Power the board (5V).
4. Run the bundled script:  `./program.sh PortableRAM8.svf`
   (wraps: openocd -f interface/ftdi/tigard.cfg, jtag newtap -irlen 10
    -expected-id 0x0150203f, svf <file>)

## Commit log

2026-07-18 v3 board: MODEL jumper, bank LEDs, pull-down resistors, sequential population
    - MODEL jumper (JP1): open=M5120 full 8MB, closed=M5126 cap at 6MB to
    avoid SLOT_CS0 conflict with backlit display controller
    - 4 green latching LEDs (D1–D4) — CPLD registered macrocell latches ON
    when each 2MB bank is confirmed at boot; power-cycle clears
    - 16× 10KΩ pull-downs (R5–R20) on SD0–SD15 to prevent ghost RAM reads
    on unpopulated banks
    - Sequential bank population: U1+U5=2MB, U2+U6=4MB, U3+U7=6MB, U4+U8=8MB
    (no SIZE jumper needed)
    - Firmware recompiled for v3 (WinCUPL + Wine, prjbureau SVF) 2026-07-17
    - Gerbers regenerated after component renumbering
    - README rewritten for v3 features an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
    [PortableRAM-8MB-BOM.csv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]
2026-07-18 Fix CPLD LED pin assignments: move LED1/2/3 from dedicated input pins to valid I/O pins
    Pins 37/38/39 on ATF1502ASL TQFP-44 are dedicated input-only pins with no output
    driver. Declaring registered outputs (LED1/2/3) there caused the fitter to fail all
    PREASSIGN=KEEP passes and fall back to IGNORE, scrambling every pin assignment.
    - firmware/PortableRAM8.pld: LED1 pin 37->42, LED2 pin 38->43, LED3 pin 39->44
    - PortableRAM-8MB.kicad_sch: reconnected LED1/2/3 nets to pins 42/43/44; X on 37/38/39
    - PortableRAM-8MB.kicad_pcb: netlist updated, traces rerouted to pads 42/43/44
    - firmware/PortableRAM8.jed/.fit/.svf: recompiled; fitter now succeeds PREASSIGN=KEEP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
    [PortableRAM-8MB-B_Cu.gbr, PortableRAM-8MB-B_Mask.gbr, PortableRAM-8MB-B_Paste.gbr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]
2026-07-18 Update .pin file to reflect corrected LED pin assignments (Jul 18 compile)
    Replaces the stale Jul 17 .pin file (IGNORE-mode scrambled assignments)
    with the Jul 18 recompile output: LED1=42, LED2=43, LED3=44, LED0=35,
    all other signals matching the PCB netlist.
2026-07-27 firmware rev 02: add DTACK/EXT_DTACK outputs on pins 23/24
    Pins 23 and 24 (adjacent, bottom side of TQFP-44) drive /DTACK and
    /EXT_DTACK to J3 header (to be added to schematic/PCB). Both tristated
    when not our cycle (DTACK.OE = active) to avoid GLU contention.
    Purely combinatorial — immune to sleep/wake state loss.
2026-07-27 firmware rev 02: fix EXT_DTACK pin 24→31 (24 is GND on ATF1502ASL)
    Pin 24 is a physical GND pad on the TQFP-44 package. EXT_DTACK
    moved to pin 31, the other free I/O pad on the same package side.
    DTACK stays on pin 23. Both routed to J3 header (to be added to PCB).
2026-07-27 Add J3 PDS header (1x2, 2.54mm): DTACK→pin 23, EXT_DTACK→pin 31
    Schematic: added Conn_01x02 J3 with nets DTACK_OUT/EXT_DTACK_OUT
    wired to U9 CPLD pins 23 and 31. Removed no-connect markers from
    those pads.
    PCB: placed J3 on board edge, routed U9 pad 23→J3 pin 1 (DTACK)
    and U9 pad 31→J3 pin 2 (EXT_DTACK). DRC clean: 0 errors,
    0 unconnected pads.
    User connects J3 pin 1 to PDS B7 (/DTACK) with a removable wire.
    No more soldering to CPLD pads.
    [PortableRAM-8MB-B_Cu.gbr, PortableRAM-8MB-B_Mask.gbr, PortableRAM-8MB-B_Paste.gbr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]
2026-07-27 README: document J3 DTACK header, v2-validated benchmark results
    - What's new table: add J3 DTACK header row vs v2 bodge wire
    - BOM: add J3 (1x2 2.54mm, PDS DTACK header)
    - Assembly: add J3 to solder order
    - Replace old sleep/wake bring-up note with full DTACK fix section
    including v2-validated benchmark table (Speedometer 1.486→2.170,
    Snooper 51%→102%, post-sleep collapse eliminated)
    - References: credit Reza Fouladian for DTACK/PDS guidance
2026-07-27 fix: swap J1↔J2 to match v2 convention; add J3 to BOM
    v3 had J1=JTAG and J2=RAM connector — reversed from v2.
    Correct convention (matching v2): J1=RAM connector (Samtec),
    J2=JTAG header, J3=DTACK header.
    Updated schematic, PCB, BOM CSV, and README throughout.
    Also added missing J3 PDS DTACK header row to BOM CSV.
    [PortableRAM-8MB-BOM.csv, PortableRAM-8MB.kicad_pcb, PortableRAM-8MB.kicad_sch]
2026-07-27 regen Gerbers after J1/J2 silkscreen swap
    Gerbers.zip and all Gerber files regenerated 2026-07-27 to reflect
    corrected J1=RAM connector, J2=JTAG header silkscreen labels.
    [PortableRAM-8MB-B_Cu.gbr, PortableRAM-8MB-B_Mask.gbr, PortableRAM-8MB-B_Paste.gbr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]
2026-07-27 add CPL file for JLCPCB PCBA
    58 SMD components with X/Y centroid, rotation, and layer.
    Through-hole (J1/J2/J3/JP1) and test point (TP1) excluded —
    these are hand-soldered after PCBA.
    [PortableRAM-8MB-CPL.csv]
2026-07-27 fix BOM for JLCPCB: expand designator ranges, rename Ref->Designator
    JLCPCB requires individual comma-separated designators (U1,U2,...U8)
    not hyphenated ranges (U1-U8). Also renames header Ref->Designator
    to match JLCPCB's expected column name.
    [PortableRAM-8MB-BOM.csv]
2026-07-27 docs: add PDS slot photo with /DTACK (B7) location marked
    Annotated photo of Mac Portable logic board showing PDS connector
    (red) and RAM connector (blue) with /DTACK pin B7 called out.
2026-07-27 firmware rev 02: compiled outputs with DTACK on pins 23 and 31
    Recompiled from PortableRAM8.pld rev 02 (2026-07-26).
    DTACK → pin 23, EXT_DTACK → pin 31, LEDs → pins 42/43/44/35.
    All PREASSIGN=KEEP assignments confirmed in .fit report.
2026-07-27 rename firmware files to PortableRAM8_v3.*; fix BUILD.md
    All firmware files renamed: PortableRAM8.* → PortableRAM8_v3.*
    BUILD.md updated: correct username (matthew), accurate compile
    commands with full paths, module path for fuseconv, v3-specific
    description replacing old v2 reference.
    program.sh and README updated to match new filenames.
2026-07-27 rename BOM, CPL, Gerbers.zip to include v3 in filename
    PortableRAM-8MB-BOM.csv → PortableRAM-8MB-v3-BOM.csv
    PortableRAM-8MB-CPL.csv → PortableRAM-8MB-v3-CPL.csv
    Gerbers.zip → PortableRAM-8MB-v3-Gerbers.zip
    README updated to match.
    [PortableRAM-8MB-v3-BOM.csv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]
2026-07-28 fix schematic design note errors
    R6-R21 → R5-R20 (pull-downs are R5-R20; R21 is /AS pull-up)
    R22-R25 → R1-R4 (LED series resistors are R1-R4 in v3)
    DTACK note: updated to reflect CPLD drives /DTACK via pin 23 → J3 → PDS B7
    [PortableRAM-8MB.kicad_sch]
